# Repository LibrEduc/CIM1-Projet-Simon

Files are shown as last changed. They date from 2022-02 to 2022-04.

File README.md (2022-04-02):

# CIM1-Projet-Simon
A "Simon says" project, CMS components, ATTtiny1634 microcontroller.

Un projet Simon, u "Jacques a dit", en composants CMS, ave un microcontrôleur ATTtiny1634.

## Objectif

Projet de (re)création d'un jeu du Simon MB (c), ou bien appelé "Simon says". Après avoir analysé le principe du jeu, le but est de tout refaire en électronique microprogrammée, le plus petit possible et de fabriquer un boîtier ajusté.

## Goal

Project to (re)create a game of the Simon MB (c), also called "Simon says". After having analysed the principle of the game, the goal is to remake everything in microprogrammed electronics, as small as possible, and to make a fitted box.
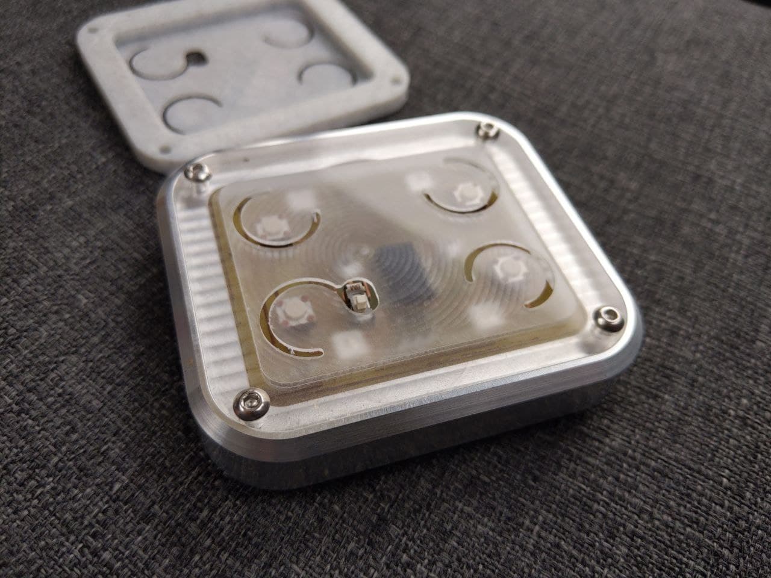
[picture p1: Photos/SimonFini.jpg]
Simon fini


## Liste des pièces / Bill of Materials
- Condensateur C-EUC1206
- Support pile
- MicroContrôleur
- Connecteur ISP
- Led Neopixel
- Mosfet canal N
- Résistance
- Buzzer 5v 2,3kHz 50ma
- Bouton poussoir
- Interrupteur

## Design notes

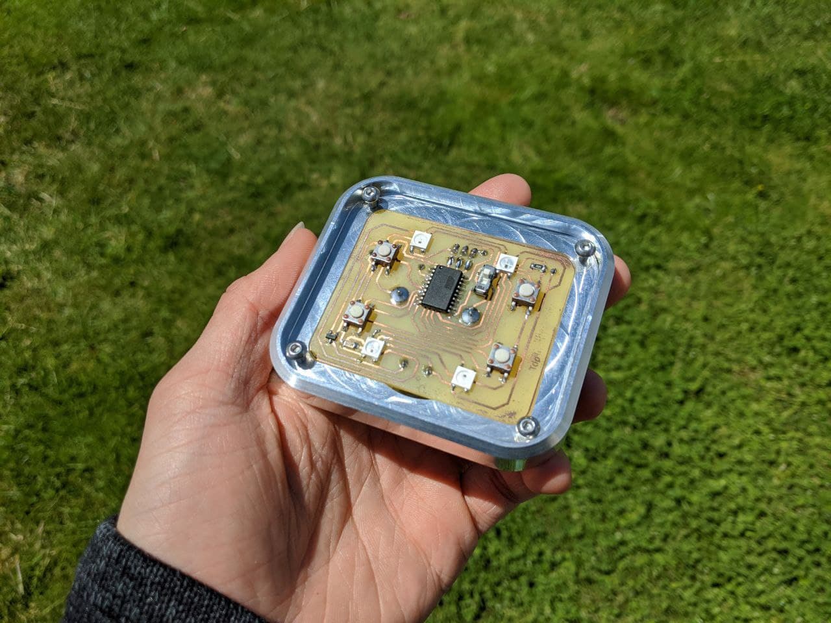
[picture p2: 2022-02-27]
Photos/AjustementPCB.jpg

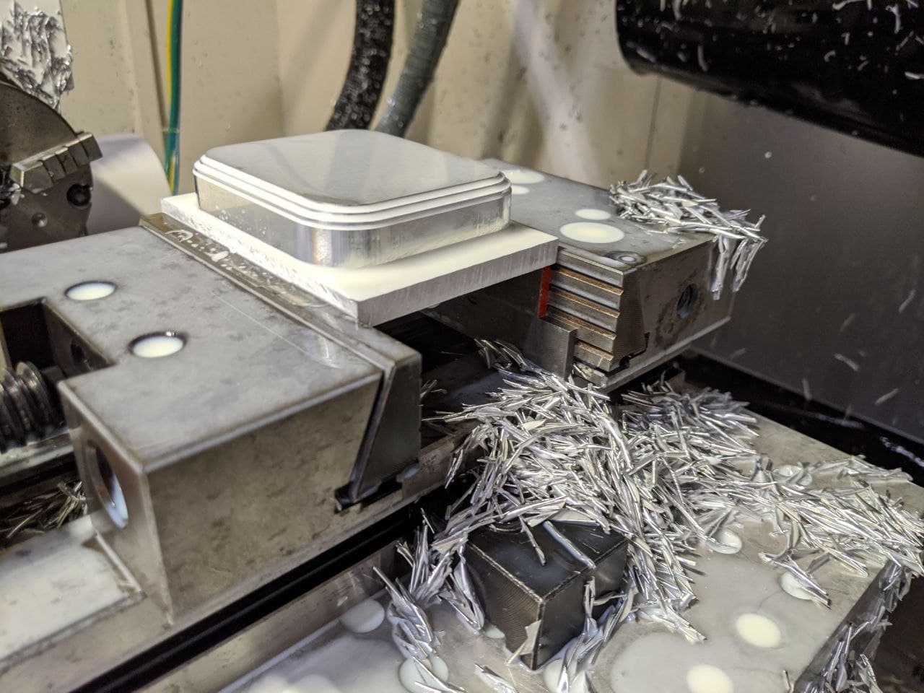
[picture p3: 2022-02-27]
Photos/Usinage en une passe.jpg

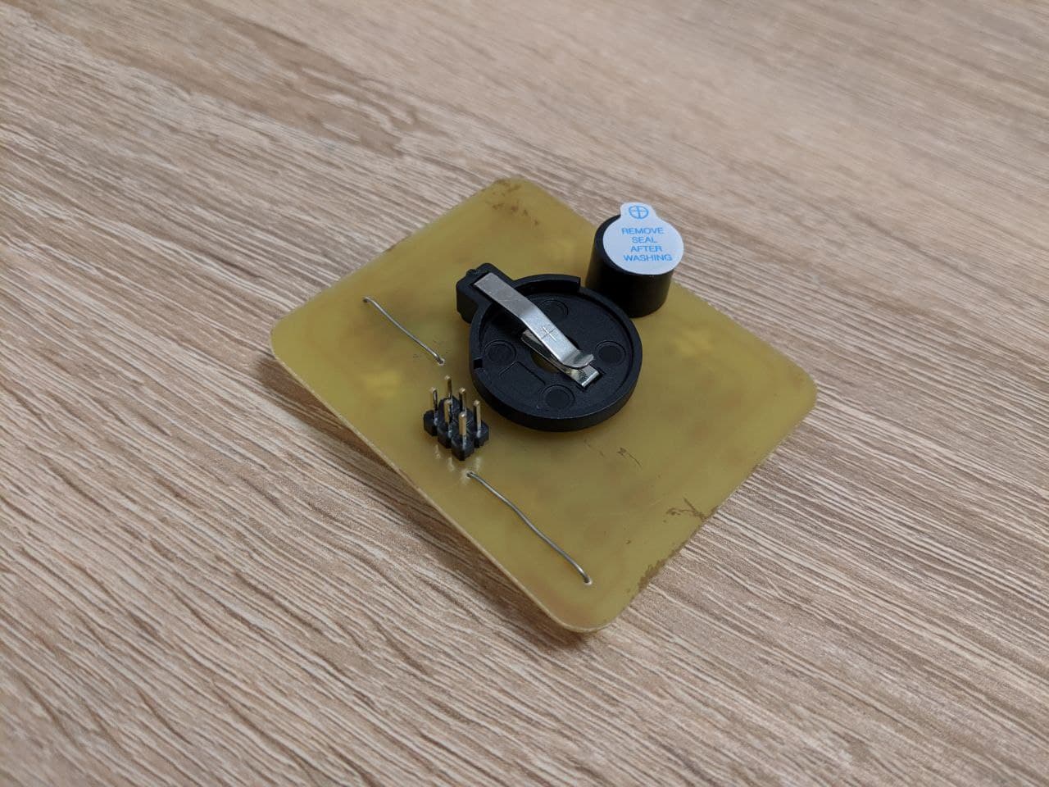
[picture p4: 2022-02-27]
Photos/PCB seul verso.jpg

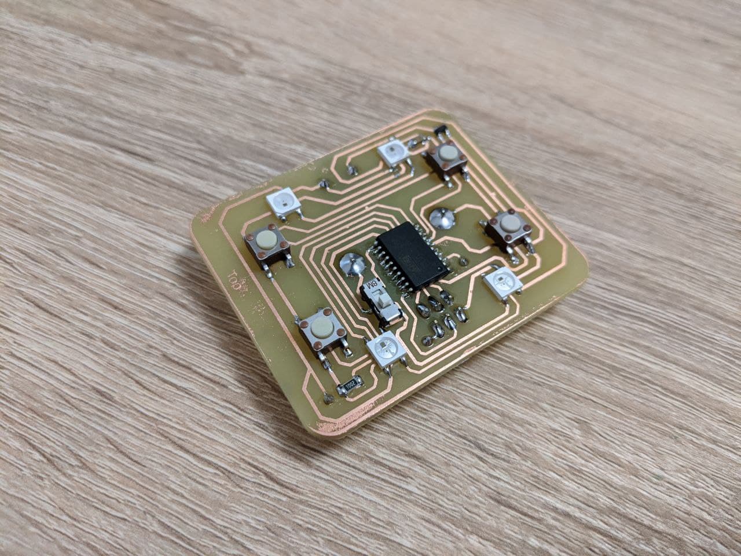
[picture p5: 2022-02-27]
Photos/PCB seul.jpg

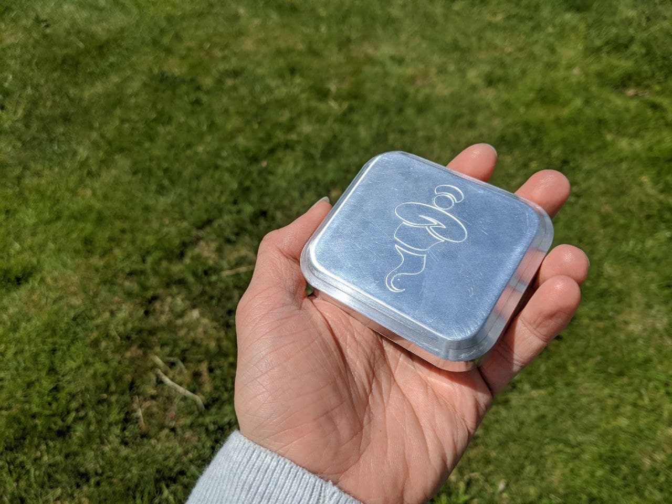
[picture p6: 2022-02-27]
Photos/SimonFiniVerso.jpg

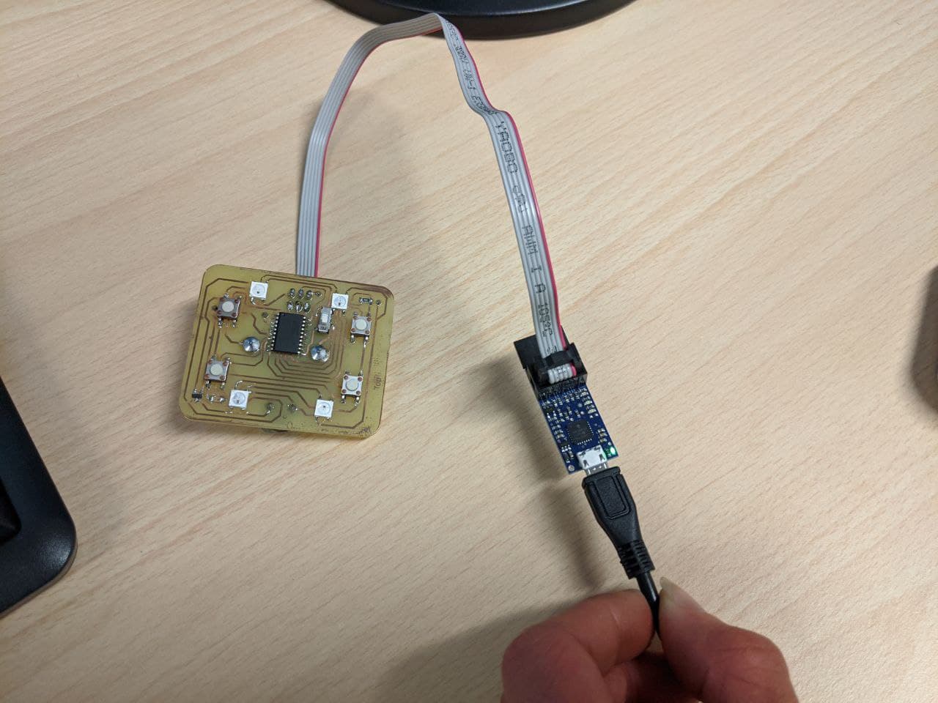
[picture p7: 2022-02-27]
Photos/Programmateur ISP.jpg

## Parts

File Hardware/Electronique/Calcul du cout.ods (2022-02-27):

 |  |  | 1 exemplaire |  |  |  | 100 exemplaires
Désignation | Site | Référence | Unité de vente | Prix unitaire | Quantité | Total | Unité de vente | Prix unitaire | Quantité | Total
Condensateur C-EUC1206 | Farnell (https://fr.farnell.com/avx/12065c104k4t2a/condensateur-0-1-f-50v-10-x7r/dp/2579015) | 12065C104K4T2A | 10 | 0,10 € | 10 | 0,99 € | 10 | 0,08 € | 100 | 8,07 €
Support pile | Farnell (https://fr.farnell.com/multicomp-pro/mp000362/support-batterie-2032-traversant/dp/3126601) | MP000362 | 50 | 26,08 € | 1 | 26,08 € | 50 | 20,87 € | 2 | 41,74 €
MicroContrôleur | Farnell (https://fr.farnell.com/microchip/attiny1634r-su/microcontroller-mcu-8-bit-attiny/dp/2695549) | ATTINY1634R-SU | 1 | 1,76 € | 1 | 1,76 € | 1 | 1,50 € | 100 | 150,00 €
Connecteur ISP | Farnell (https://fr.farnell.com/multicomp/mc-254-06-00-st-dip/connecteur-header-6-voies-2-rangs/dp/2843525) | MC-254-06-00-ST-DIP | 10 | 0,16 € | 10 | 1,63 € | 10 | 0,16 € | 100 | 16,30 €
Led Neopixel | GoTronic (https://www.gotronic.fr/art-10-leds-rgb-cms-neopixel-ada1655-22884.htm) | 16909 | 10 | 5,80 € | 1 | 5,80 € | 10 | 5,80 € | 40 | 232,00 €
Mosfet canal N | Farnell (https://fr.farnell.com/diodes-inc/bs170f/transistor-mosfet-canal-n-sot/dp/9526005RL) | BS170F | 10 | 0,55 € | 10 | 5,46 € | 10 | 0,34 € | 100 | 34,40 €
Résistance | Farnell (https://fr.farnell.com/rohm/ltr18ezpj103/res-10k-5-0-75w-1206-couche-epaisse/dp/3254956) | LTR18EZPJ103 | 10 | 0,12 € | 10 | 1,21 € | 10 | 0,05 € | 100 | 4,81 €
Buzzer 5v 2,3kHz 50ma | GoTronic (https://www.gotronic.fr/art-buzzer-sv12-5hq-30818.htm) | 5459 | 1 | 1,80 € | 1 | 1,80 € | 1 | 1,80 € | 100 | 180,00 €
Bouton poussoir | Farnell (https://fr.farnell.com/alcoswitch-te-connectivity/fsm2jsmaa/commut-tactile-spst-0-05a-24v/dp/3133602) | FSM2JSMAA | 10 | 0,13 € | 10 | 1,29 € | 10 | 0,13 € | 400 | 51,60 €
Intérrupteur | Farnell (https://fr.farnell.com/panasonic/evqp7a01p/interr-tactile-spst-no-0-05a-12v/dp/2860916) | EVQP7A01P | 10 | 0,18 € | 10 | 1,80 € | 10 | 0,18 € | 100 | 18,00 €
 |  |  |  | TOTAL 1 Simon |  | 47,82 € |  | TOTAL 100 Simon |  | 736,92 €
 |  |  |  |  |  |  |  | Prix rapporté à 1 Simon |  | 7,37 €

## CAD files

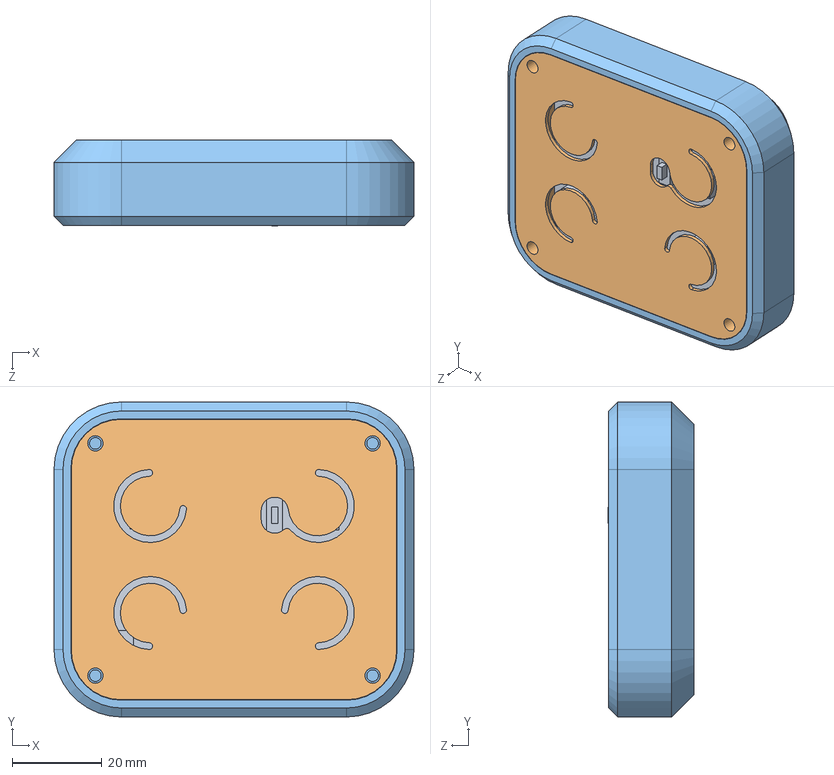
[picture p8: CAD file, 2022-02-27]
Hardware/Boîtier/Version Usiné/AssemblageSimonV5.SLDASM
80.0 x 70.0 x 19.2 mm
VraiPcb
Couvercle^AssemblageSimonV5
Corps^AssemblageSimonV5

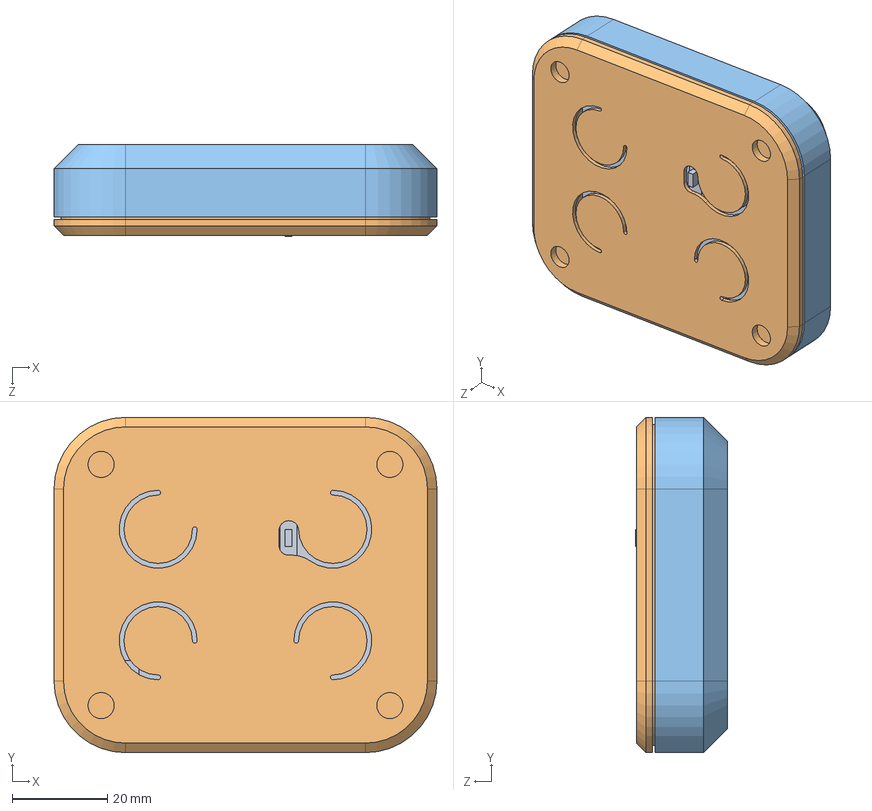
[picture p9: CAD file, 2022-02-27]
Hardware/Boîtier/Version Imprimé en 3d/AssemblageSimonV3.SLDASM
80.3 x 70.3 x 19.2 mm
VraiPcb
Couvercle
Fond

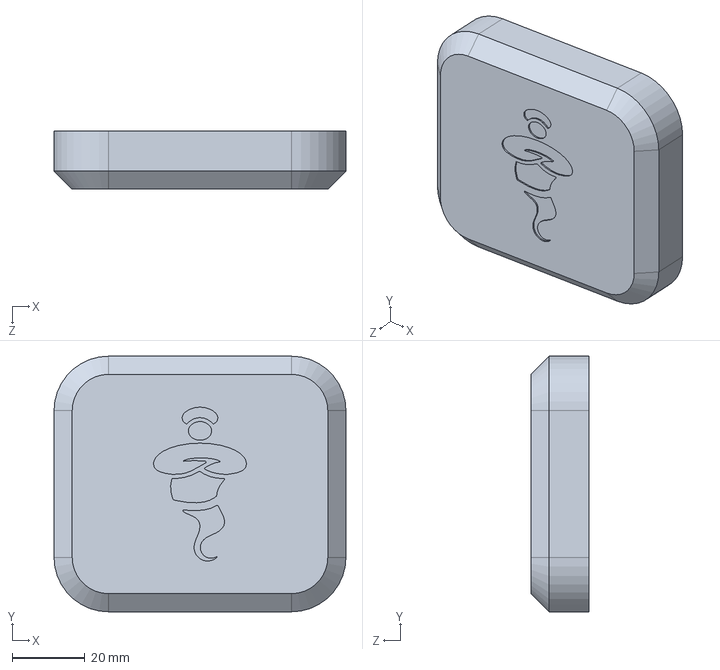
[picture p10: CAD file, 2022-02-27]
Hardware/Boîtier/Version Imprimé en 3d/Fond.sldprt
80.3 x 70.3 x 16.1 mm

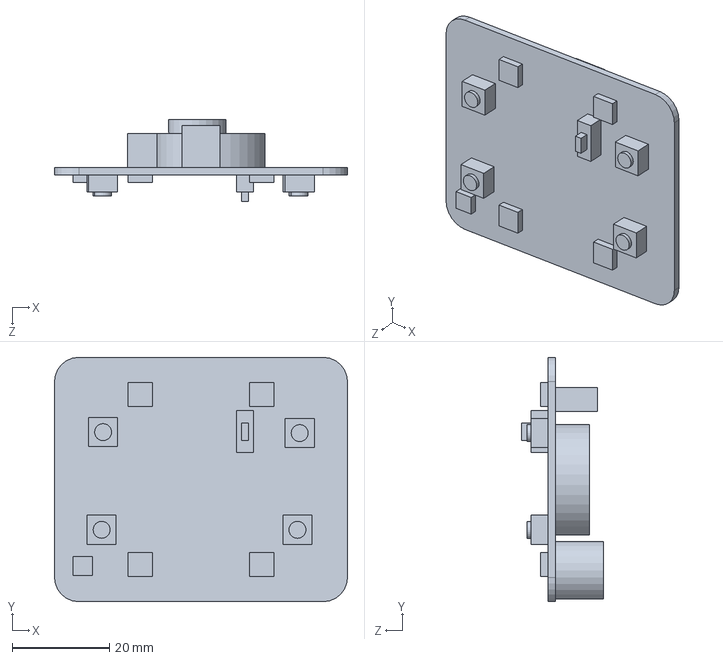
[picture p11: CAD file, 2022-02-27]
Hardware/Boîtier/Version Usiné/VraiPcb.SLDPRT
60.3 x 50.3 x 17.0 mm

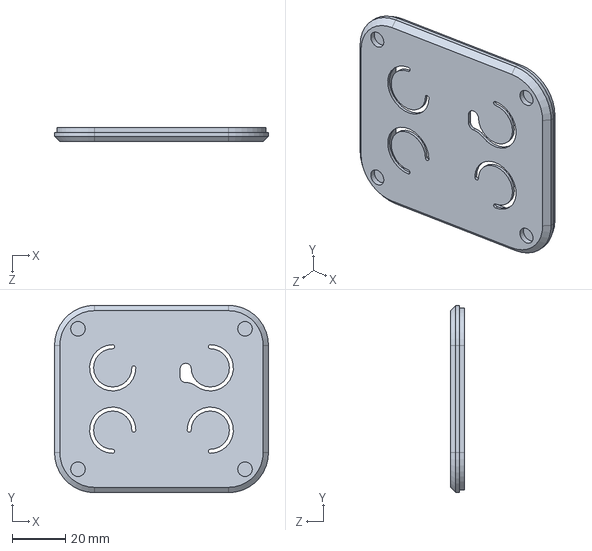
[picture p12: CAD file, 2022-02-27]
Hardware/Boîtier/Version Imprimé en 3d/Couvercle.sldprt
80.3 x 70.3 x 5.32 mm

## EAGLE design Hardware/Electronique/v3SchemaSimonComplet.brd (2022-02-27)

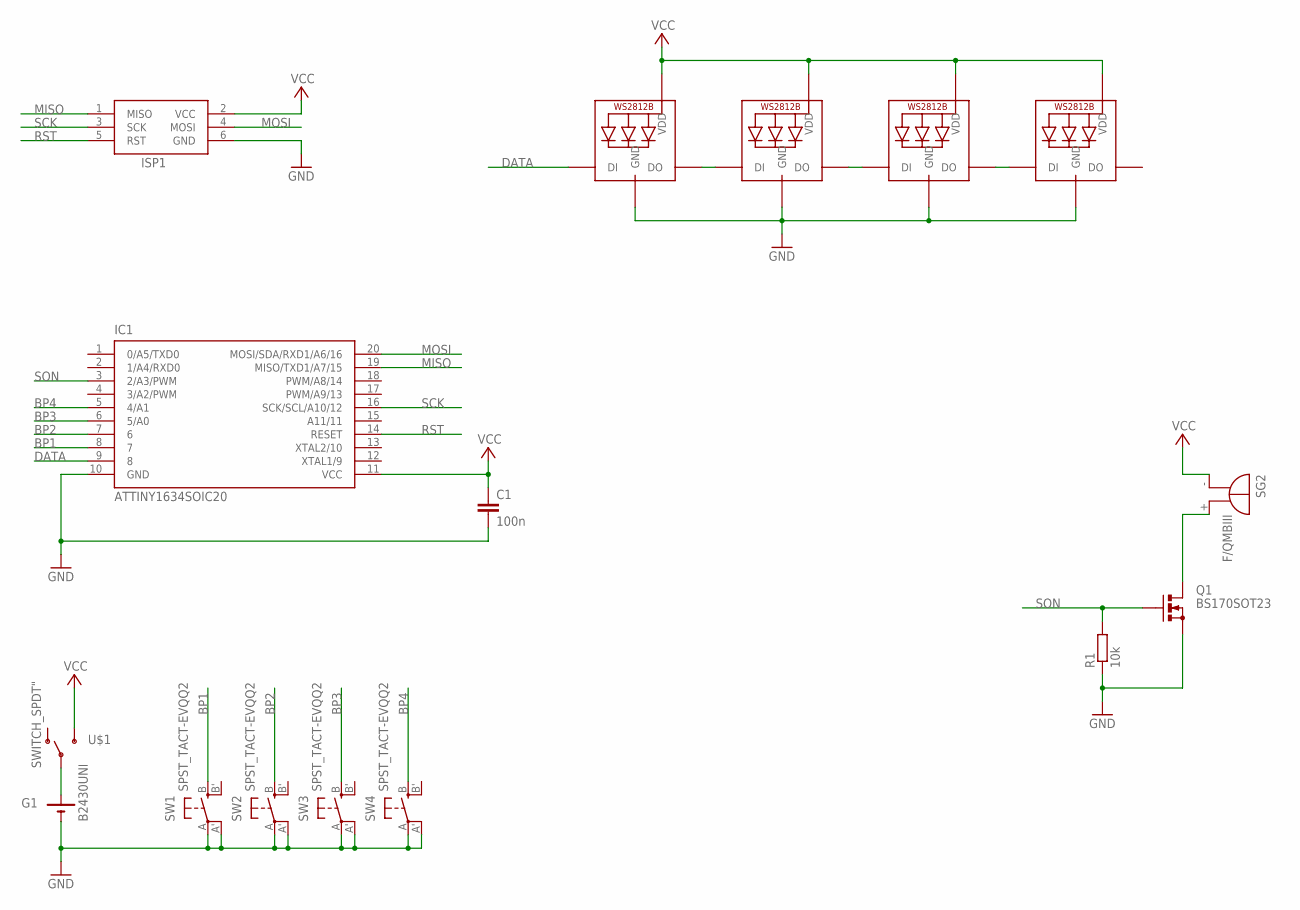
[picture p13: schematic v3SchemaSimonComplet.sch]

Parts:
C1: 100n; C1206
G1: B2430UNI
IC1: ATTINY1634SOIC20; SOIC20
ISP1: AVRISP-6; AVRISP
LED1, LED2, LED3, LED4: WS2812B5050; WS2812B
Q1: BS170SOT23; SOT23
R1: 10k; R1206
SG2: F/QMBIII
SW1, SW2, SW3, SW4: SPST_TACT-EVQQ2; EVQ-Q2
U$1: SWITCH_SPDT"; CMS-CL-SB-12A-02T

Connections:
BP1: IC1.8 (7), SW1.B (S)
BP2: IC1.7 (6), SW2.B (S)
BP3: IC1.6 (5/A0), SW3.B (S)
BP4: IC1.5 (4/A1), SW4.B (S)
DATA: IC1.9 (8), LED1.4-DIN (DI)
GND: C1.2, G1.-@1 (-), IC1.10 (GND), ISP1.6 (GND), LED1.3-GND (GND), LED2.3-GND (GND), LED3.3-GND (GND), LED4.3-GND (GND), Q1.2 (S), R1.1, SW1.A, SW1.A' (P1), SW2.A, SW2.A' (P1), SW3.A, SW3.A' (P1), SW4.A, SW4.A' (P1)
MISO: IC1.19 (MISO/TXD1/A7/15), ISP1.1 (MISO)
MOSI: IC1.20 (MOSI/SDA/RXD1/A6/16), ISP1.4 (MOSI)
unnamed: LED1.2-DOUT (DO), LED2.4-DIN (DI)
unnamed: LED2.2-DOUT (DO), LED3.4-DIN (DI)
unnamed: LED3.2-DOUT (DO), LED4.4-DIN (DI)
unnamed: G1.+@1 (+), U$1.2
unnamed: Q1.3 (D), SG2.+ (-)
RST: IC1.14 (RESET), ISP1.5 (RST)
SCK: IC1.16 (SCK/SCL/A10/12), ISP1.3 (SCK)
SON: IC1.3 (2/A3/PWM), Q1.1 (G), R1.2
VCC: C1.1, IC1.11 (VCC), ISP1.2 (VCC), LED1.1-VDD (VDD), LED2.1-VDD (VDD), LED3.1-VDD (VDD), LED4.1-VDD (VDD), SG2.- (+), U$1.3 (S)

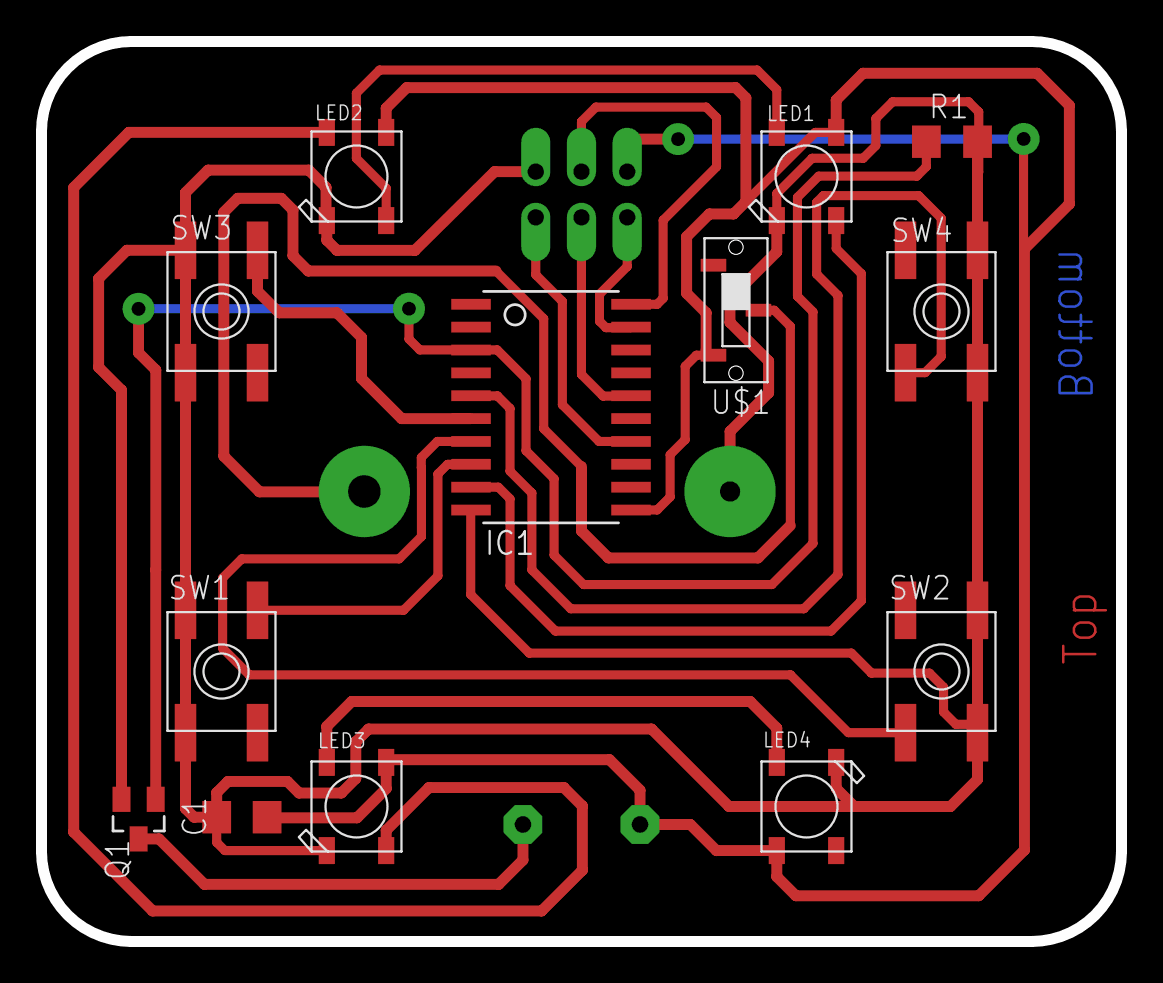
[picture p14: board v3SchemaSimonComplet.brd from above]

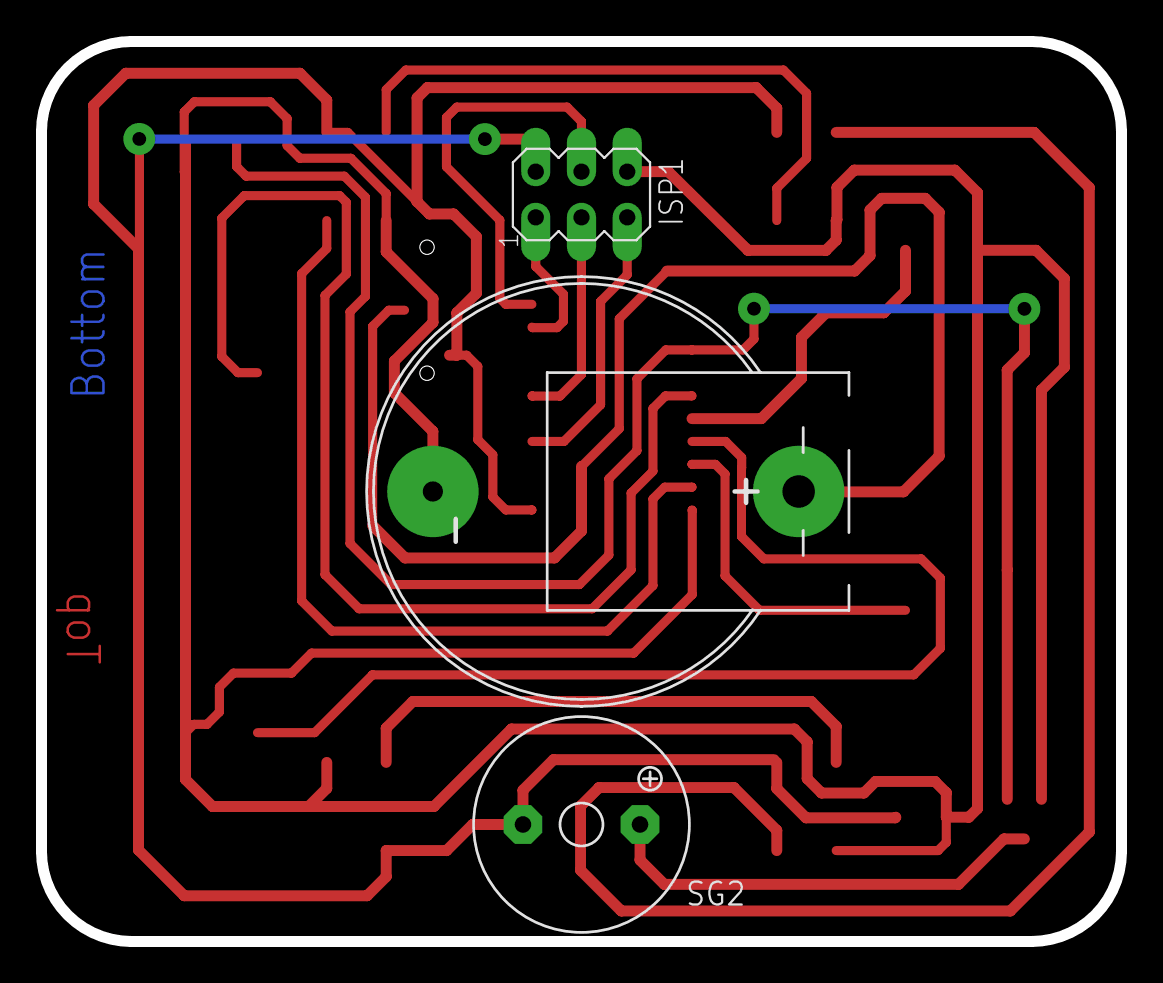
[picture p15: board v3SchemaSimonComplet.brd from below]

Board: 2 copper layers, 60.0 x 50.0 mm, 16 parts (3 on the bottom side), 17 nets.

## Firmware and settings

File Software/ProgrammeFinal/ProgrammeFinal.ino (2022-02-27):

/* Ce programme est légèrement différent du programme tinkercad n°17:
 *  Les numéros des broches utilisés ont été mis à jour.
 *  La fréquence des led NeoPixel a été adapté pour fonctionner avec celle réellement utilisé
*/

#define buzzerPin 2 // Le buzzer est connecté à la broche n°8
int buttonNumber = 0; // Variable contenant le numéro du bouton pressé, 0 signifiant qu'aucun bouton n'est actionné
#define button0 4
int button0CurrentState = 0;
int button0PreviousState = 1;
#define button1 5
int button1CurrentState = 0;
int button1PreviousState = 1;
#define button2 7
int button2CurrentState = 0;
int button2PreviousState = 1;
#define button3 6
int button3CurrentState = 0;
int button3PreviousState = 1;

int SimonSequence[6] = {0, 1, 2, 3, 0, 1};
int SequenceLenght = 1;
bool lost = 0;


// https://html-color-codes.info/ Roue de couleurs hex
#include <Adafruit_NeoPixel.h> // Importation de la bibliothèque pour gérer les NeoPixels
#define NeoPixelPin 8 // Broche sur laquelle les NeoPixels sont connectées
#define PixelCount 4 // Nombre de NeoPixel
Adafruit_NeoPixel MyLed = Adafruit_NeoPixel(PixelCount, NeoPixelPin, NEO_GRB + NEO_KHZ400); // Affectation des paramètres définies ci-dessus.

void OnLed(int ledNumber) { // Procédure prenant le numéro d'une led en paramètre et allumant la led correspondante
  switch (ledNumber) {
    case 0:
      MyLed.setPixelColor(ledNumber, MyLed.Color(150, 0, 0)); // Si la led n°0 est demandé, elle est configuré en rouge
      tone(buzzerPin, 252);
      break;
    case 1:
      MyLed.setPixelColor(ledNumber, MyLed.Color(0, 150, 0)); // Si la led n°1 est demandé, elle est configuré en vert
      tone(buzzerPin, 209);
      break;
    case 2:
      MyLed.setPixelColor(ledNumber, MyLed.Color(0, 0, 150)); // Si la led n°2 est demandé, elle est configuré en bleu
      tone(buzzerPin, 415);
      break;
    case 3:
      MyLed.setPixelColor(3, 0xFFFF00); // Si la led n°3 est demandé, elle est configuré en jaune
      tone(buzzerPin, 310);
      break;
  }
  MyLed.show(); // // Allumer la led configuré
  delay(420); // Pendant 420ms
  noTone(buzzerPin);
  MyLed.clear(); // Configurer toutes les led en "noir" (Equivalent de: MyLed.setPixelColor(broche, MyLed.Color(0, 0, 0));)
  MyLed.show(); // Eteindre toutes les led
  delay(50); // Pendant 50ms
}

void SimonShow() {
  int showed = 0;
  while (showed < SequenceLenght) {
    OnLed(SimonSequence[showed]);
    showed++;
  }
}

int buttonState() {
  button0CurrentState = digitalRead(button0); // Récupérer l'état actuel du bouton
  button1CurrentState = digitalRead(button1); // Récupérer l'état actuel du bouton
  button2CurrentState = digitalRead(button2); // Récupérer l'état actuel du bouton
  button3CurrentState = digitalRead(button3); // Récupérer l'état actuel du bouton

  if (button0CurrentState != button0PreviousState) { // Si cet état a changé
    if (button0CurrentState == LOW) { // Si cet état est passé de haut à bas (C'est inversé à cause du PullUp)
      Serial.println("Pression bouton n0"); // C'est que le bouton est pressé, falling edge
      OnLed(0);
    }
    else { // Si cet état est passé de bas à haut
      Serial.println("Depression bouton n0"); // C'est que le bouton est relaché, rising edge
      buttonNumber = 0;
    }
    delay(50); // Debounce ?
    button0PreviousState = button0CurrentState; // Fin de l'action, cet état fait donc désormais parti du passé
  }

  else if (button1CurrentState != button1PreviousState) { // Si cet état a changé
    if (button1CurrentState == LOW) { // Si cet état est passé de haut à bas (C'est inversé à cause du PullUp)
      Serial.println("Pression bouton n1"); // C'est que le bouton est pressé, falling edge
      OnLed(1);
    }
    else { // Si cet état est passé de bas à haut
      Serial.println("Depression bouton n1"); // C'est que le bouton est relaché, rising edge
      buttonNumber = 1;
    }
    delay(50); // Debounce ?
    button1PreviousState = button1CurrentState; // Fin de l'action, cet état fait donc désormais parti du passé
  }
  else if (button2CurrentState != button2PreviousState) { // Si cet état a changé
    if (button2CurrentState == LOW) { // Si cet état est passé de haut à bas (C'est inversé à cause du PullUp)
      Serial.println("Pression bouton n2"); // C'est que le bouton est pressé, falling edge
      OnLed(2);
    }
    else { // Si cet état est passé de bas à haut
      Serial.println("Depression bouton n2"); // C'est que le bouton est relaché, rising edge
      buttonNumber = 2;
    }
    delay(50); // Debounce ?
    button2PreviousState = button2CurrentState; // Fin de l'action, cet état fait donc désormais parti du passé
  }
  else if (button3CurrentState != button3PreviousState) { // Si cet état a changé
    if (button3CurrentState == LOW) { // Si cet état est passé de haut à bas (C'est inversé à cause du PullUp)
      Serial.println("Pression bouton n3"); // C'est que le bouton est pressé, falling edge
      OnLed(3);
    }
    else { // Si cet état est passé de bas à haut
      Serial.println("Depression bouton n3"); // C'est que le bouton est relaché, rising edge
      buttonNumber = 3;
    }
    delay(50); // Debounce ?
    button3PreviousState = button3CurrentState; // Fin de l'action, cet état fait donc désormais parti du passé
  }
  else { // Revient à dire "Si ni le bouton n°0, ni le n°1, ni le n°2, ni le n°3 n'est pressé c'est que qu'aucun bouton n'est pressé"
    buttonNumber = 4;
  }
  return (buttonNumber); // Lorsque la procédure est executé elle retournera le numéro du bouton pressé contenu dans la variable "buttonNumber"
}

void SimonCheck() {
  int checkedNumber = 0; // Initaliser une variable permettant de vérifier que tout les chiffres de la séquence ont été pressé
  while (checkedNumber < SequenceLenght) { // Tant que tout les chiffres de la séquence n'ont pas été pressé
    buttonNumber = buttonState(); // Etre attentif à la pression des boutons
    if (buttonNumber != 4) { // Si un bouton est pressé
      if (buttonNumber == SimonSequence[checkedNumber]) { // Et que c'est le bon au regard de la séquence
        checkedNumber ++; // Passer au nombre suivant de la séquence
      }
      else { // Sinon, c'est que le mauvais bouton est pressé
        lost = 0;
      }
    }
  }
}

void setup() {
  Serial.begin(9600);
  pinMode(button0, INPUT_PULLUP);
  pinMode(button1, INPUT_PULLUP);
  pinMode(button2, INPUT_PULLUP);
  pinMode(button3, INPUT_PULLUP);
  MyLed.begin(); // Initialiser la bibliothèque
}

void loop() {
  lost = 1; // 1 pas perdu 0 perdu
  SequenceLenght = 1;
  
  for (int i = 0; i < 6; i++) {
      randomSeed(analogRead(11));
      SimonSequence[i] = random(0, 4); // Générer un chiffre aléatoire et le stocker dans la case i du tableau
  }

  while (SequenceLenght <= 6 && lost == 1) {
    SimonShow();
    SimonCheck();
    SequenceLenght++;
    delay(800); // Pause de 800ms avant de jouer la prochaine séquence
  }
  if (lost == 0) {
    Serial.println("Vous avez perdu");
    tone(buzzerPin, 42);
    delay(1500);
    noTone(buzzerPin);
  }
  else {
    Serial.println("Vous avez gagne");
  }
  delay(3000);
}

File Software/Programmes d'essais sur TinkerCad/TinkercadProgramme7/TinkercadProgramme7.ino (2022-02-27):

#include <Adafruit_NeoPixel.h> // Importation de la bibliothèque pour gérer les NeoPixels
#define BrocheNeoPixel 2 // Broche sur laquelle les NeoPixels sont connectées
#define NombrePixel 4 // Nombre de NeoPixel
Adafruit_NeoPixel MesLed = Adafruit_NeoPixel(NombrePixel, BrocheNeoPixel, NEO_GRB + NEO_KHZ800); // Affectation des paramètres définies ci-dessus.

#define button1 3 // Il y a 4 boutons, le premier est nommé "button1" puis connecté à la broche n°3
#define button2 4
#define button3 5
#define button4 6
int buttonNumber = 0; // Variable contenant le numéro du bouton pressé, 0 signifiant qu'aucun bouton n'est actionné
#define buzzerPin 8 // Le buzzer est connecté à la broche n°8

void setup() {
  MesLed.begin(); // Initialiser la bibliothèque
  pinMode(button1, INPUT_PULLUP); // Déclaration des broches associées aux boutons en tant qu'entré. Utilisation d'une résistance de tirage interne
  pinMode(button2, INPUT_PULLUP);
  pinMode(button3, INPUT_PULLUP);
  pinMode(button4, INPUT_PULLUP);
  pinMode(buzzerPin, OUTPUT); // La broche utilisé par le buzzer est configuré en tant que sortie
}

int button() {
  if (digitalRead(button1) == LOW) { // Si le premier bouton est à l'état bas c'est qu'il est pressé
    buttonNumber = 1; // Stocker le numéro du bouton pressé dans cette variable
  }
  else if (digitalRead(button2) == LOW) {
    buttonNumber = 2;
  }
  else if (digitalRead(button3) == LOW) {
    buttonNumber = 3;
  }
  else if (digitalRead(button4) == LOW) {
    buttonNumber = 4;
  }
  else { // Revient à dire "Si ni le bouton n°1, ni le n°2, ni le n°3, ni le n°4 n'est pressé c'est que qu'aucun bouton n'est pressé"
    buttonNumber = 0;
  }
  return (buttonNumber); // Lorsque la procédure est executé elle retournera le numéro du bouton pressé contenu dans la variable "buttonNumber"
}

void buzzer() {
  switch (buttonNumber) { // On s'intéresse à la valeur stocké dans la variable buttonNumber
    case 1: // Si elle vaut 1 c'est que le premier bouton est pressé
      tone(buzzerPin, 110); // Jouer un Là à 110Hz
      break;
    case 2:
      tone(buzzerPin, 220);
      break;
    case 3:
      tone(buzzerPin, 440);
      break;
    case 4:
      tone(buzzerPin, 880);
      break;
    default: // Si elle ne vaut ni 1, ni 2, ni 3, ni 4, c'est qu'elle vaut 0 donc aucun bouton n'est pressé
      noTone(buzzerPin); // Eteindre le buzzer
      break;
  }
}

void led() {
  switch (buttonNumber) { // On s'intéresse à la valeur stocké dans la variable buttonNumber
    case 1: // Si elle vaut 1 c'est que le premier bouton est pressé
      MesLed.setPixelColor(0, MesLed.Color(150, 0, 0)); // Alors, la led n°0 sera verte
      break;
    case 2:
      MesLed.setPixelColor(1, MesLed.Color(0, 150, 0));
      break;
    case 3:
      MesLed.setPixelColor(2, MesLed.Color(0, 0, 150));
      break;
    case 4:
      MesLed.setPixelColor(3, 0xFFFF00);
      break;
    default: // Si elle ne vaut ni 1, ni 2, ni 3, ni 4, c'est qu'elle vaut 0 donc aucun bouton n'est pressé
      MesLed.setPixelColor(0, MesLed.Color(0, 0, 0)); // Alors les led doivent-être éteintes
      MesLed.setPixelColor(1, MesLed.Color(0, 0, 0));
      MesLed.setPixelColor(2, MesLed.Color(0, 0, 0));
      MesLed.setPixelColor(3, MesLed.Color(0, 0, 0));
      break;
  }

}

void loop() {
  buttonNumber = button(); // Executer la fonction qui va lire l'état des boutons et l'enregistrer dans la variable buttonNumber
  buzzer(); // Executer la procédure qui va jouer un son en fonction du bouton pressé
  led(); // Executer la procédure pour déterminer les leds à allumer
  MesLed.show(); // Allumer les led ou plus précisement rafraichir l'état des led
}

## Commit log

2022-02-27 Commit Inital
    [AssemblageSimonV3.SLDASM, AssemblageSimonV5.SLDASM, Calcul du cout.ods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]
2022-02-27 Ajout de photos
